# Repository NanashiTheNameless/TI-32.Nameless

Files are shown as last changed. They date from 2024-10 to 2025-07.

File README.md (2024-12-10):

# TI-32

## NamelessNanashi version with erroring towards my personal preferences, no warranty of any kind, not yet tested, DO NOT EXPECT TO WORK PERFECTLY YET

built pcb

"Buy Me A Coffee" (https://buymeacoffee.com/contactchrh)

## Documentation

Read the DOCUMENTATION.md file

## Video

YouTube (https://www.youtube.com/watch?v=Bicjxl4EcJg)

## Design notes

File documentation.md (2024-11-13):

# ESP32 Code Deployment and Server Setup Documentation

## 1. Downloading Code to the ESP32

1. **Open the Arduino IDE**:
   - Open the `.ino` file located in the `esp32` directory using the Arduino IDE.

2. **Configure Secrets**:
   - Navigate to the `secrets.h` file.
   - Fill in the required information (such as WiFi credentials, Hardware Pins, etc.) as specified by your project.

3. **Obtain Server IP Address**:
   - Refer to the [Server Setup](#3-running-the-server) section to get the IP address of your server.
   - Update the IP address in your `secrets.h` to match the server IP.

4. **Flash the ESP32**:
   - Follow the hardware documentation to upload the code to your ESP32.

## 2. Wiring Instructions

1. **Add Wiring Picture**:
   _(Insert image here)_

2. **Wiring Configuration**:
   - Wiring configurations may vary depending on the ESP32 model you're using.
   - Refer to your specific hardware's datasheet for pin configurations.

## 3. Running the Server

1. **Prerequisites**:
   - Ensure you have [Node.js](https://nodejs.org/) and npm (Node Package Manager) installed on your machine.

2. **Install Server Dependencies**:
   - Navigate to the `server` directory in your terminal or command prompt.
   - Run the following command to install the necessary dependencies:

     ```bash
     npm install
     ```

3. **Start the Server**:
   - To run the server, execute the following command:

     ```bash
     node index.mjs
     ```

## 4. Retrieving Your Server IP Address

To obtain the server's IP address (required for configuration in `secrets.h`):

### On Windows

1. Open the Command Prompt by searching for "cmd" in the start menu or pressing `Win + R` and typing `cmd`.
2. Run the following command:

   ```bash
   ipconfig
   ```

3. Locate your specific network adapter (e.g., Wi-Fi or Ethernet).
4. Use the IPv4 address associated with that network adapter. This will be the server's IP address.

---

### Additional Notes

- Ensure your ESP32 and server are connected to the same network.
- If you encounter issues with the server or ESP32 connectivity, verify firewall settings and network configurations.

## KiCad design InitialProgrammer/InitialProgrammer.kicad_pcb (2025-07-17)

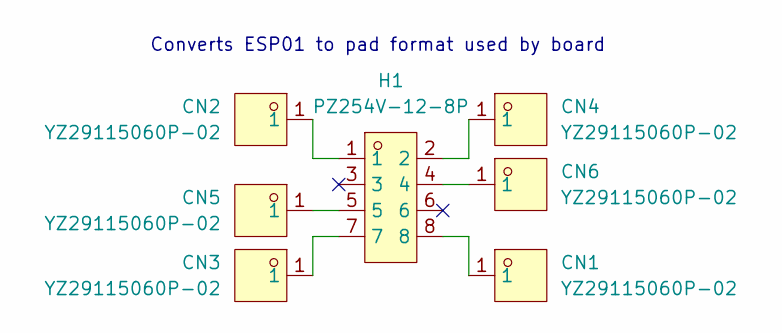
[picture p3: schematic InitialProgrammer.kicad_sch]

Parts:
CN1, CN2, CN3, CN4, CN5, CN6: YZ29115060P-02; TESTPOINT-SMD_BD2.0-D0.7; LCSC Part C5157350
H1: PZ254V-12-8P; HDR-TH_8P-P2.54-V-M-R2-C4-S2.54; LCSC Part C492421

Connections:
unnamed: CN1.1, H1.8
unnamed: CN2.1, H1.1
unnamed: CN3.1, H1.7
unnamed: CN4.1, H1.2
unnamed: CN5.1, H1.5
unnamed: CN6.1, H1.4

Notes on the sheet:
Converts ESP01 to pad format used by board

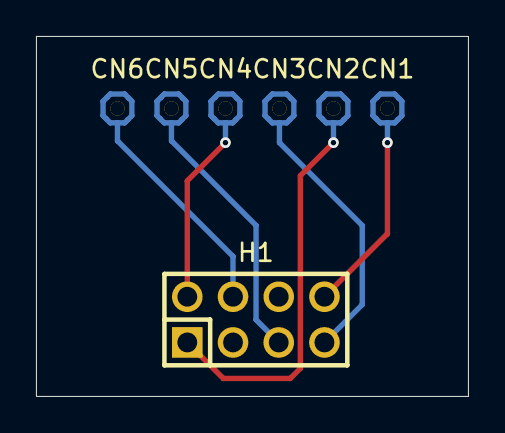
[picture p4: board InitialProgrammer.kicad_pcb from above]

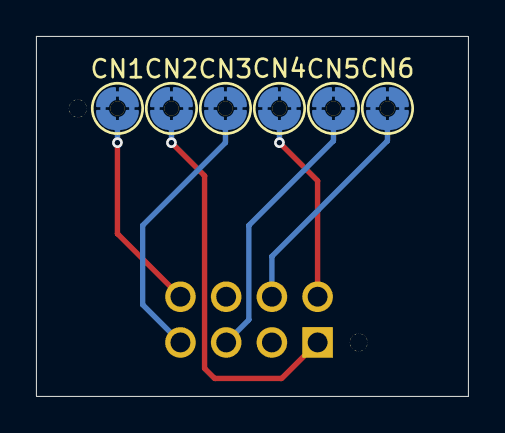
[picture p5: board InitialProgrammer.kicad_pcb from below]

Board: 2 copper layers, 24.0 x 20.0 mm, 7 parts (6 on the bottom side), 6 nets.

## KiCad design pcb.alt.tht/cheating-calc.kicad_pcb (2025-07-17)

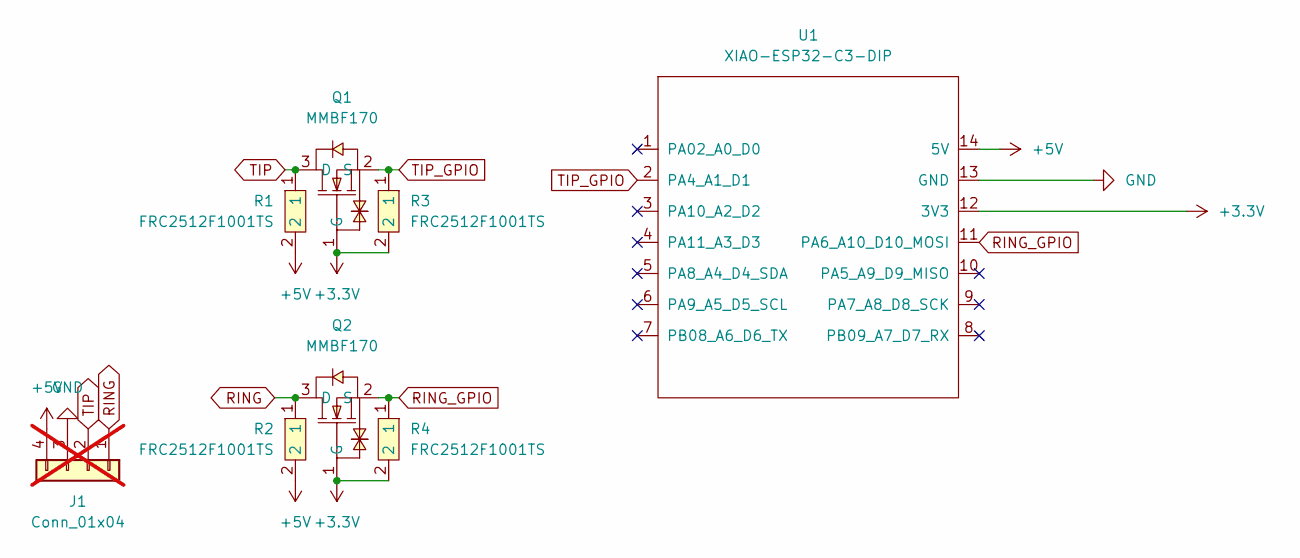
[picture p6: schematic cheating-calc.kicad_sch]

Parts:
J1: Conn_01x04; PinHeader_1x04_P2.54mm_Vertical; not fitted
Q1, Q2: MMBF170; SOT-23-3_L2.9-W1.6-P1.90-LS2.8-BR; LCSC Part C130879
R1, R2, R3, R4: FRC2512F1001TS; R2512; LCSC Part C2960683
U1: XIAO-ESP32-C3-DIP

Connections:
+3.3V: Q1.1 (G), Q2.1 (G), R3.2, R4.2, U1.12 (3V3)
+5V: J1.4, R1.2, R2.2, U1.14 (5V)
GND: J1.3, U1.13 (GND)
RING: J1.1, Q2.3 (D), R2.1
RING_GPIO: Q2.2 (S), R4.1, U1.11 (PA6_A10_D10_MOSI)
TIP: J1.2, Q1.3 (D), R1.1
TIP_GPIO: Q1.2 (S), R3.1, U1.2 (PA4_A1_D1)

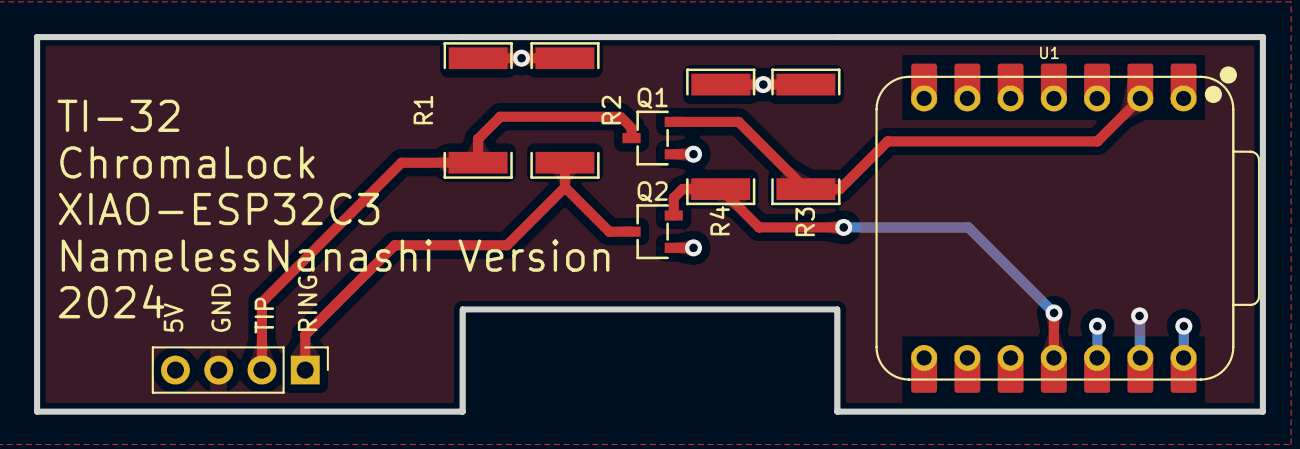
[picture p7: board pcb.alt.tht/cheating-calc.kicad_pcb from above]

Board: 2 copper layers, 72.0 x 22.0 mm, 8 parts (0 on the bottom side), 7 nets.

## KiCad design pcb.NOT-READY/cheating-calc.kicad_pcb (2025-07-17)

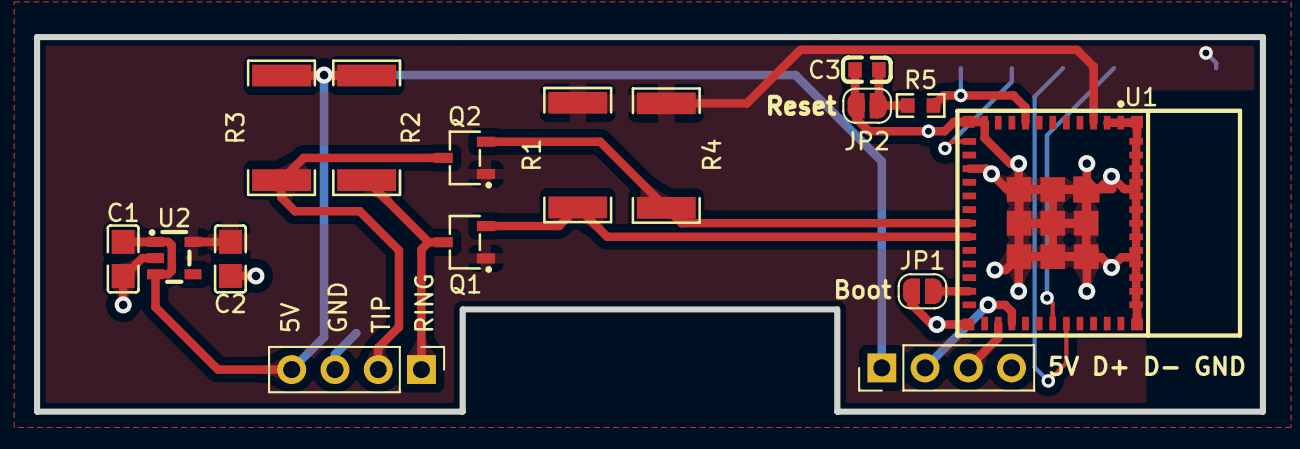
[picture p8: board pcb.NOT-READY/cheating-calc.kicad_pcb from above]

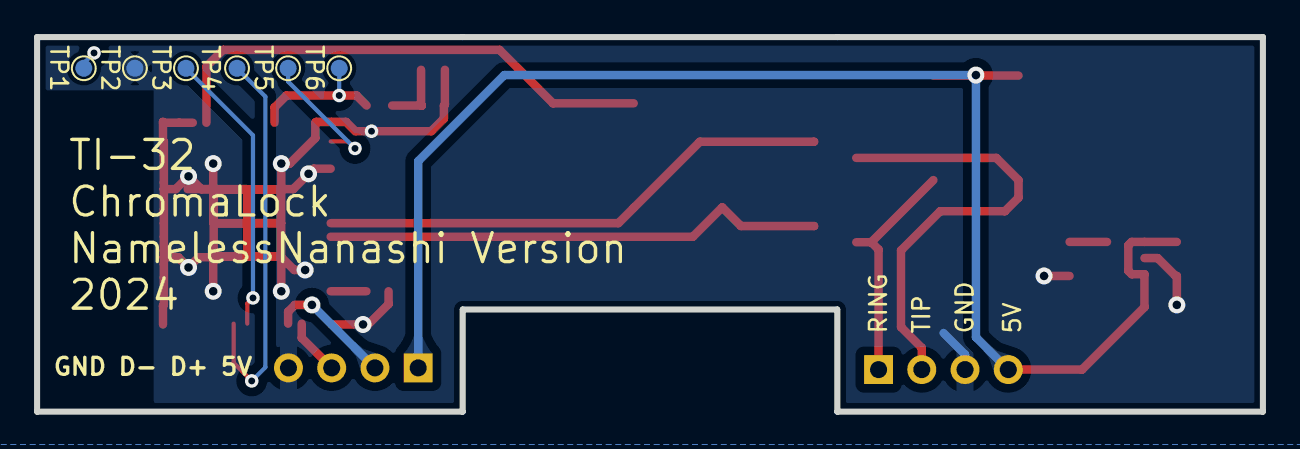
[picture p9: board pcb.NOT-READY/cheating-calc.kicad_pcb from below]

Board: 2 copper layers, 72.0 x 22.0 mm, 22 parts (6 on the bottom side), 15 nets.

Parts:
C1, C2: CL21B105KPFNNNE; C0805
C3: CC0603KRX7R9BB104; C0603
J1, J2: Conn_01x04; PinHeader_1x04_P2.54mm_Vertical
JP1, JP2: SolderJumper_2_Open; SolderJumper-2_P1.3mm_Open_RoundedPad1.0x1.5mm
Q1, Q2: MMBF170; SOT-23-3_L2.9-W1.6-P1.90-LS2.8-BR
R1, R2, R3, R4: FRC2512F1001TS; R2512
R5: 0603WAF1002T5E; R0603
TP1, TP2, TP3, TP4, TP5, TP6: TestPoint; TestPoint_Pad_D1.0mm
U1: ESP32-C3-MINI-1-N4; WIFIM-SMD_ESP32-C3-MINI-1
U2: TPLP5907MFX-3.3; SOT-23-5_L2.9-W1.6-P0.95-LS2.8-BR

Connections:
+3.3V: C2.1, Q1.1 (G), Q2.1 (G), R1.2, R4.2, TP1.1, U1.3 (3V3), U2.5 (VOUT)
+5V: C1.1, J1.4, J2.1, R2.2, R3.2, U2.1 (VIN), U2.3 (EN)
/D+: J2.2, U1.27 (IO19)
/D-: J2.3, U1.26 (IO18)
GND: C1.2, C2.2, C3.1, J1.3, J2.4, JP1.1 (A), JP2.1 (A), TP2.1, U1.1 (GND), U1.2 (GND), U1.11 (GND), U1.14 (GND), U1.36 (GND), U1.37 (GND), U1.38 (GND), U1.39 (GND), U1.40 (GND), U1.41 (GND), U1.42 (GND), U1.43 (GND), U1.44 (GND), U1.45 (GND), U1.46 (GND), U1.47 (GND), U1.48 (GND), U1.49 (GND), U1.50 (GND), U1.51 (GND), U1.52 (GND), U1.53 (GND), U2.2 (GND)
unnamed: JP1.2 (B), U1.23 (IO9)
unnamed: C3.2, JP2.2 (B), R5.1
unnamed: R5.2, TP6.1, U1.8 (EN)
unnamed: TP5.1, U1.12 (IO0)
unnamed: TP3.1, U1.30 (RXD0)
unnamed: TP4.1, U1.31 (TXD0)
RING: J1.1, Q1.3 (D), R2.1
RING_GPIO: Q1.2 (S), R1.1, U1.19 (IO5)
TIP: J1.2, Q2.3 (D), R3.1
TIP_GPIO: Q2.2 (S), R4.1, U1.18 (IO4)

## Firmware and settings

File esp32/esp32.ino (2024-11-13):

// Project: TI-32 v0.1
// Author:  ChromaLock
// Date:    2024

#include "./secrets.h"
#include "./launcher.h"
#include <TICL.h>
#include <CBL2.h>
#include <TIVar.h>
#include <WiFi.h>
#include <WiFiClientSecure.h>
#include <WiFiClient.h>
#include <HTTPClient.h>
#include <UrlEncode.h>
#include <Preferences.h>

// #define CAMERA

#ifdef CAMERA
#include <esp_camera.h>
#define CAMERA_MODEL_XIAO_ESP32S3
#include "./camera_pins.h"
#include "./camera_index.h"
#endif

constexpr auto TIP = D1;
constexpr auto RING = D10;
constexpr auto MAXHDRLEN = 16;
constexpr auto MAXDATALEN = 4096;
constexpr auto MAXARGS = 5;
constexpr auto MAXSTRARGLEN = 256;
constexpr auto PICSIZE = 756;
constexpr auto PICVARSIZE = PICSIZE + 2;
constexpr auto PASSWORD = 69420;

CBL2 cbl;
Preferences prefs;

// whether or not the user has entered the password
bool unlocked = false;

// Arguments
int currentArg = 0;
char strArgs[MAXARGS][MAXSTRARGLEN];
double realArgs[MAXARGS];

// the command to execute
int command = -1;
// whether or not the operation has completed
bool status = 0;
// whether or not the operation failed
bool error = 0;
// error or success message
char message[MAXSTRARGLEN];
// list data
constexpr auto LISTLEN = 256;
constexpr auto LISTENTRYLEN = 20;
char list[LISTLEN][LISTENTRYLEN];
// http response
constexpr auto MAXHTTPRESPONSELEN = 4096;
char response[MAXHTTPRESPONSELEN];
// image variable (96x63)
uint8_t frame[PICVARSIZE] = {PICSIZE & 0xff, PICSIZE >> 8};
String fullResponse;
const int PAGE_SIZE = 100;
int PAGE_PAGE = 0; 

void connect();
void disconnect();
void gpt();
void send();
void launcher();
void snap();
void solve();
void image_list();
void fetch_image();
void fetch_chats();
void send_chat();
void program_list();
void fetch_program();
void sendPage();
void reply();
void clearChat(); 

struct Command
{
  int id;
  const char *name;
  int num_args;
  void (*command_fp)();
  bool wifi;
};

struct Command commands[] = {
    {0, "connect", 0, connect, false},
    {1, "disconnect", 0, disconnect, false},
    {2, "gpt", 1, gpt, true},
    {4, "send", 2, send, true},
    {5, "launcher", 0, launcher, false},
    {7, "snap", 0, snap, false},
    {8, "solve", 1, solve, true},
    {9, "image_list", 1, image_list, true},
    {10, "fetch_image", 1, fetch_image, true},
    {11, "fetch_chats", 2, fetch_chats, true},
    {12, "send_chat", 2, send_chat, true},
    {13, "program_list", 1, program_list, true},
    {14, "fetch_program", 1, fetch_program, true},
    { 15, "sendPage", 1, sendPage, true },
    { 16, "reply", 1, reply, true },
    { 17, "clearChat", 1, clearChat, true}, 
};

constexpr int NUMCOMMANDS = sizeof(commands) / sizeof(struct Command);
constexpr int MAXCOMMAND = 14;

uint8_t header[MAXHDRLEN];
uint8_t data[MAXDATALEN];

// lowercase letters make strings weird,
// so we have to truncate the string
void fixStrVar(char *str)
{
  int end = strlen(str);
  for (int i = 0; i < end; ++i)
  {
    if (isLowerCase(str[i]))
    {
      --end;
    }
  }
  str[end] = '\0';
}

int onReceived(uint8_t type, enum Endpoint model, int datalen);
int onRequest(uint8_t type, enum Endpoint model, int *headerlen,
              int *datalen, data_callback *data_callback);

void startCommand(int cmd)
{
  command = cmd;
  status = 0;
  error = 0;
  currentArg = 0;
  for (int i = 0; i < MAXARGS; ++i)
  {
    memset(&strArgs[i], 0, MAXSTRARGLEN);
    realArgs[i] = 0;
  }
  strncpy(message, "no command", MAXSTRARGLEN);
}

void setError(const char *err)
{
  Serial.print("ERROR: ");
  Serial.println(err);
  error = 1;
  status = 1;
  command = -1;
  strncpy(message, err, MAXSTRARGLEN);
}

void setSuccess(const char *success)
{
  Serial.print("SUCCESS: ");
  Serial.println(success);
  error = 0;
  status = 1;
  command = -1;
  strncpy(message, success, MAXSTRARGLEN);
}

int sendProgramVariable(const char *name, uint8_t *program, size_t variableSize);

bool camera_sign = false;

void setup()
{
  Serial.begin(115200);
   Serial.println("delay");
    delay(2000); 
  Serial.println("[CBL]");
  delay(1000);

  cbl.setLines(TIP, RING);
  cbl.resetLines();
  cbl.setupCallbacks(header, data, MAXDATALEN, onReceived, onRequest);
  // cbl.setVerbosity(true, (HardwareSerial *)&Serial);

  pinMode(TIP, INPUT);
  pinMode(RING, INPUT);

  Serial.println("[preferences]");
  prefs.begin("ccalc", false);
  auto reboots = prefs.getUInt("boots", 0);
  Serial.print("reboots: ");
  Serial.println(reboots);
  prefs.putUInt("boots", reboots + 1);
  prefs.end();

#ifdef CAMERA
  Serial.println("[camera]");

  camera_config_t config;
  config.ledc_channel = LEDC_CHANNEL_0;
  config.ledc_timer = LEDC_TIMER_0;
  config.pin_d0 = Y2_GPIO_NUM;
  config.pin_d1 = Y3_GPIO_NUM;
  config.pin_d2 = Y4_GPIO_NUM;
  config.pin_d3 = Y5_GPIO_NUM;
  config.pin_d4 = Y6_GPIO_NUM;
  config.pin_d5 = Y7_GPIO_NUM;
  config.pin_d6 = Y8_GPIO_NUM;
  config.pin_d7 = Y9_GPIO_NUM;
  config.pin_xclk = XCLK_GPIO_NUM;
  config.pin_pclk = PCLK_GPIO_NUM;
  config.pin_vsync = VSYNC_GPIO_NUM;
  config.pin_href = HREF_GPIO_NUM;
  config.pin_sscb_sda = SIOD_GPIO_NUM;
  config.pin_sscb_scl = SIOC_GPIO_NUM;
  config.pin_pwdn = PWDN_GPIO_NUM;
  config.pin_reset = RESET_GPIO_NUM;
  config.xclk_freq_hz = 20000000;
  config.frame_size = FRAMESIZE_UXGA;
  // this needs to be pixformat grayscale in the future
  config.pixel_format = PIXFORMAT_JPEG; // for streaming
  config.grab_mode = CAMERA_GRAB_WHEN_EMPTY;
  config.fb_location = CAMERA_FB_IN_PSRAM;
  config.jpeg_quality = 12;
  config.fb_count = 1;

  // if PSRAM IC present, init with UXGA resolution and higher JPEG quality
  //                      for larger pre-allocated frame buffer.
  if (config.pixel_format == PIXFORMAT_JPEG)
  {
    if (psramFound())
    {
      config.jpeg_quality = 10;
      config.fb_count = 2;
      config.grab_mode = CAMERA_GRAB_LATEST;
    }
    else
    {
      // Limit the frame size when PSRAM is not available
      config.frame_size = FRAMESIZE_SVGA;
      config.fb_location = CAMERA_FB_IN_DRAM;
    }
  }
  else
  {
    // Best option for face detection/recognition
    config.frame_size = FRAMESIZE_240X240;
#if CONFIG_IDF_TARGET_ESP32S3
    config.fb_count = 2;
#endif
  }

  // camera init
  esp_err_t err = esp_camera_init(&config);
  if (err != ESP_OK)
  {
    Serial.printf("Camera init failed with error 0x%x\n", err);
    return;
  }
  else
  {
    Serial.println("camera ready");
    camera_sign = true; // Camera initialization check passes
  }

  sensor_t *s = esp_camera_sensor_get();
  // enable grayscale
  s->set_special_effect(s, 2);
#endif

  strncpy(message, "default message", MAXSTRARGLEN);
  delay(100);
  memset(data, 0, MAXDATALEN);
  memset(header, 0, 16);
  Serial.println("[ready]");
}

void (*queued_action)() = NULL;

void loop()
{
  if (queued_action)
  {
    // dont ask me why you need this, but it fails otherwise.
    // probably relates to a CBL2 timeout thing?
    delay(1000);
    Serial.println("executing queued actions");
    // dont ask me
    void (*tmp)() = queued_action;
    queued_action = NULL;
    tmp();
  }
  if (command >= 0 && command <= MAXCOMMAND)
  {
    for (int i = 0; i < NUMCOMMANDS; ++i)
    {
      if (commands[i].id == command && commands[i].num_args == currentArg)
      {
        if (commands[i].wifi && !WiFi.isConnected())
        {
          setError("wifi not connected");
        }
        else
        {
          Serial.print("processing command: ");
          Serial.println(commands[i].name);
          commands[i].command_fp();
        }
      }
    }
  }
  cbl.eventLoopTick();
}

int onReceived(uint8_t type, enum Endpoint model, int datalen)
{
  char varName = header[3];

  Serial.print("unlocked: ");
  Serial.println(unlocked);

  // check for password
  if (!unlocked && varName == 'P')
  {
    auto password = TIVar::realToLong8x(data, model);
    if (password == PASSWORD)
    {
      Serial.println("successful unlock");
      unlocked = true;
      return 0;
    }
    else
    {
      Serial.println("failed unlock");
    }
  }

  if (!unlocked)
  {
    return -1;
  }

  // check for command
  if (varName == 'C')
  {
    if (type != VarTypes82::VarReal)
    {
      return -1;
    }
    int cmd = TIVar::realToLong8x(data, model);
    if (cmd >= 0 && cmd <= MAXCOMMAND)
    {
      Serial.print("command: ");
      Serial.println(cmd);
      startCommand(cmd);
      return 0;
    }
    else
    {
      Serial.print("invalid command: ");
      Serial.println(cmd);
      return -1;
    }
    
  }
      if (varName == 'V') {
    if (type != VarTypes82::VarReal) {
      return -1;
    }
    PAGE_PAGE = TIVar::realToLong8x(data, model);
    Serial.print("Received page number: ");
    Serial.println(PAGE_PAGE);
    sendPage();
    return 0;
  }

  if (varName == 'X') {
    Serial.println("Recieved var X");
    if (type != VarTypes82::VarReal) {
      Serial.println("var x not equal vartypes82:varreal");
      return -1;

    }
    Serial.println("Reset fullResponse to empty");
    fullResponse = "";
    
    return 0;
  }

  if (currentArg >= MAXARGS)
  {
    Serial.println("argument overflow");
    setError("argument overflow");
    return -1;
  }

  switch (type)
  {
  case VarTypes82::VarString:
    Serial.print("len: ");
    strncpy(strArgs[currentArg++], TIVar::strVarToString8x(data, model).c_str(), MAXSTRARGLEN);
    fixStrVar(strArgs[currentArg - 1]);
    Serial.print("Str");
    Serial.print(currentArg - 1);
    Serial.print(" ");
    Serial.println(strArgs[currentArg - 1]);
    break;
  case VarTypes82::VarReal:
    realArgs[currentArg++] = TIVar::realToFloat8x(data, model);
    Serial.print("Real");
    Serial.print(currentArg - 1);
    Serial.print(" ");
    Serial.println(realArgs[currentArg - 1]);
    break;
  default:
    // maybe set error here?
    return -1;
  }
  return 0;
}

uint8_t frameCallback(int idx)
{
  return frame[idx];
}

char varIndex(int idx)
{
  return '0' + (idx == 9 ? 0 : (idx + 1));
}

int onRequest(uint8_t type, enum Endpoint model, int *headerlen, int *datalen, data_callback *data_callback)
{
  char varName = header[3];
  char strIndex = header[4];
  char strname[5] = {'S', 't', 'r', varIndex(strIndex), 0x00};
  char picname[5] = {'P', 'i', 'c', varIndex(strIndex), 0x00};
  Serial.print("request for ");
  Serial.println(varName == 0xaa ? strname : varName == 0x60 ? picname
                                                             : (const char *)&header[3]);
  memset(header, 0, sizeof(header));
  switch (varName)
  {
  case 0x60:
    if (type != VarTypes82::VarPic)
    {
      return -1;
    }
    *datalen = PICVARSIZE;
    TIVar::intToSizeWord(*datalen, &header[0]);
    header[2] = VarTypes82::VarPic;
    header[3] = 0x60;
    header[4] = strIndex;
    *data_callback = frameCallback;
    break;
  case 0xAA:
    if (type != VarTypes82::VarString)
    {
      return -1;
    }
    // TODO right now, the only string variable will be the message, but ill need to allow for other vars later
    *datalen = TIVar::stringToStrVar8x(String(message), data, model);
    TIVar::intToSizeWord(*datalen, header);
    header[2] = VarTypes82::VarString;
    header[3] = 0xAA;
    // send back as same variable that was requested
    header[4] = strIndex;
    *headerlen = 13;
    break;
  case 'E':
    if (type != VarTypes82::VarReal)
    {
      return -1;
    }
    *datalen = TIVar::longToReal8x(error, data, model);
    TIVar::intToSizeWord(*datalen, header);
    header[2] = VarTypes82::VarReal;
    header[3] = 'E';
    header[4] = '\0';
    *headerlen = 13;
    break;
  case 'S':
    if (type != VarTypes82::VarReal)
    {
      return -1;
    }
    *datalen = TIVar::longToReal8x(status, data, model);
    TIVar::intToSizeWord(*datalen, header);
    header[2] = VarTypes82::VarReal;
    header[3] = 'S';
    header[4] = '\0';
    *headerlen = 13;
    break;
  default:
    return -1;
  }
  return 0;
}

int makeRequest(String url, char *result, int resultLen, size_t *len)
{
  memset(result, 0, resultLen);

#ifdef SECURE
  WiFiClientSecure client;
  client.setInsecure();
#else
  WiFiClient client;
#endif
  HTTPClient http;
  http.setAuthorization(HTTP_USERNAME, HTTP_PASSWORD);

  Serial.println(url);
  http.begin(client, url.c_str());

  // Send HTTP GET request
  int httpResponseCode = http.GET();
  Serial.print(url);
  Serial.print(" ");
  Serial.println(httpResponseCode);

  int responseSize = http.getSize();
  WiFiClient *httpStream = http.getStreamPtr();

  Serial.print("response size: ");
  Serial.println(responseSize);

  if (httpResponseCode != 200)
  {
    return httpResponseCode;
  }

  if (httpStream->available() > resultLen)
  {
    Serial.print("response size: ");
    Serial.print(httpStream->available());
    Serial.println(" is too big");
    return -1;
  }

  while (httpStream->available())
  {
    *(result++) = httpStream->read();
  }
  *len = responseSize;

  http.end();

  return 0;
}

void connect()
{
  const char *ssid = WIFI_SSID;
  const char *pass = WIFI_PASS;
  Serial.print("SSID: ");
  Serial.println(ssid);
  Serial.print("PASS: ");
  Serial.println("<hidden>");
  WiFi.begin(ssid, pass);
  while (WiFi.status() != WL_CONNECTED)
  {
    if (WiFi.status() == WL_CONNECT_FAILED)
    {
      setError("failed to connect");
      return;
    }
  }
  setSuccess("connected");
}

void disconnect()
{
  WiFi.disconnect(true);
  setSuccess("disconnected");
}

void clearChat() {
  fullResponse = "";
}

void reply() {
  Serial.println("Reply action initiated");
  const char* userReply = strArgs[0];
  Serial.print("prompt: ");
  Serial.println(userReply);
  // Append the user's reply to the existing conversation
  fullResponse += "| User: " + String(userReply) + "| AI: ";
  Serial.print("full response: ");
  Serial.println(fullResponse);
  // Send the updated conversation to the server
  auto url = String(SERVER) + String("/gpt/ask?question=") + urlEncode(fullResponse);
  Serial.println("made url");
  Serial.println(url);

  size_t realsize = 0;
  Serial.println("sending request");
  if (makeRequest(url, response, MAXHTTPRESPONSELEN, &realsize)) {
    setError("error making request");
    return;
  }
  Serial.println("request recieved");

  // Update fullResponse with the new AI response
  fullResponse += String(response);

  PAGE_PAGE = 0;  // Reset to first page
  sendPage();
}

void gpt() {
  const char* prompt = strArgs[0];
  Serial.print("prompt: ");
  Serial.println(prompt);

  fullResponse = "User: " + String(prompt) + " | AI: ";

  auto url = String(SERVER) + String("/gpt/ask?question=") + urlEncode(String(prompt));

  size_t realsize = 0;
  if (makeRequest(url, response, MAXHTTPRESPONSELEN, &realsize)) {
    setError("error making request");
    return;
  }

  fullResponse += String(response);
  Serial.print("Full response: ");
  Serial.println(fullResponse);

  PAGE_PAGE = 0; 
  sendPage();
}

void sendPage() {
  int start = PAGE_PAGE * PAGE_SIZE;
  String pageContent = fullResponse.substring(start, min(start + PAGE_SIZE, (int)fullResponse.length()));
  
  strncpy(message, pageContent.c_str(), MAXSTRARGLEN);
  setSuccess(message);
}

void send()
{
  const char *recipient = strArgs[0];
  const char *message = strArgs[1];
  Serial.print("sending \"");
  Serial.print(message);
  Serial.print("\" to \"");
  Serial.print(recipient);
  Serial.println("\"");
  setSuccess("OK: sent");
}

void _sendLauncher()
{
  sendProgramVariable("TI32", __launcher_var, __launcher_var_len);
}

void launcher()
{
  // we have to queue this action, since otherwise the transfer fails
  // due to the CBL2 library still using the lines
  queued_action = _sendLauncher;
  setSuccess("queued transfer");
}

void snap()
{
#ifdef CAMERA
  if (!camera_sign)
  {
    setError("camera failed to initialize");
  }
#else
  setError("pictures not supported");
#endif
}

void solve()
{
#ifdef CAMERA
  if (!camera_sign)
  {
    setError("camera failed to initialize");
  }
#else
  setError("pictures not supported");
#endif
}

void image_list()
{
  int page = realArgs[0];
  auto url = String(SERVER) + String("/image/list?p=") + urlEncode(String(page));

  size_t realsize = 0;
  if (makeRequest(url, response, MAXSTRARGLEN, &realsize))
  {
    setError("error making request");
    return;
  }

  Serial.print("response: ");
  Serial.println(response);

  setSuccess(response);
}

void fetch_image()
{
  memset(frame + 2, 0, 756);
  // fetch image and put it into the frame variable
  int id = realArgs[0];
  Serial.print("id: ");
  Serial.println(id);

  auto url = String(SERVER) + String("/image/get?id=") + urlEncode(String(id));

  size_t realsize = 0;
  if (makeRequest(url, response, MAXHTTPRESPONSELEN, &realsize))
  {
    setError("error making request");
    return;
  }

  if (realsize != PICSIZE)
  {
    Serial.print("response size:");
    Serial.println(realsize);
    setError("bad image size");
    return;
  }

  // load the image
  frame[0] = realsize & 0xff;
  frame[1] = (realsize >> 8) & 0xff;
  memcpy(&frame[2], response, 756);

  setSuccess(response);
}

void fetch_chats()
{
  int room = realArgs[0];
  int page = realArgs[1];
  auto url = String(SERVER) + String("/chats/messages?p=") + urlEncode(String(page)) + String("&c=") + urlEncode(String(room));

  size_t realsize = 0;
  if (makeRequest(url, response, MAXSTRARGLEN, &realsize))
  {
    setError("error making request");
    return;
  }

  Serial.print("response: ");
  Serial.println(response);

  setSuccess(response);
}

void send_chat()
{
  int room = realArgs[0];
  const char *msg = strArgs[1];

  auto url = String(SERVER) +
             String("/chats/send?c=") +
             urlEncode(String(room)) +
             String("&m=") +
             urlEncode(String(msg)) +
             String("&id=") +
             urlEncode(String(CHAT_NAME));

  size_t realsize = 0;
  if (makeRequest(url, response, MAXSTRARGLEN, &realsize))
  {
    setError("error making request");
    return;
  }

  Serial.print("response: ");
  Serial.println(response);

  setSuccess(response);
}

void program_list()
{
  int page = realArgs[0];
  auto url = String(SERVER) + String("/programs/list?p=") + urlEncode(String(page));

  size_t realsize = 0;
  if (makeRequest(url, response, MAXSTRARGLEN, &realsize))
  {
    setError("error making request");
    return;
  }

  Serial.print("response: ");
  Serial.println(response);

  setSuccess(response);
}

char programName[256];
char programData[4096];
size_t programLength;

void _resetProgram()
{
  memset(programName, 0, 256);
  memset(programData, 0, 4096);
  programLength = 0;
}

void _sendDownloadedProgram()
{
  if (sendProgramVariable(programName, (uint8_t *)programData, programLength))
  {
    Serial.println("failed to transfer requested download");
    Serial.print(programName);
    Serial.print("(");
    Serial.print(programLength);
    Serial.println(")");
  }
  _resetProgram();
}

void fetch_program()
{
  int id = realArgs[0];
  Serial.print("id: ");
  Serial.println(id);

  _resetProgram();

  auto url = String(SERVER) + String("/programs/get?id=") + urlEncode(String(id));

  if (makeRequest(url, programData, 4096, &programLength))
  {
    setError("error making request for program data");
    return;
  }

  size_t realsize = 0;
  auto nameUrl = String(SERVER) + String("/programs/get_name?id=") + urlEncode(String(id));
  if (makeRequest(nameUrl, programName, 256, &realsize))
  {
    setError("error making request for program name");
    return;
  }

  queued_action = _sendDownloadedProgram;

  setSuccess("queued download");
}

/// OTHER FUNCTIONS

int sendProgramVariable(const char *name, uint8_t *program, size_t variableSize)
{
  Serial.print("transferring: ");
  Serial.print(name);
  Serial.print("(");
  Serial.print(variableSize);
  Serial.println(")");

  int dataLength = 0;

  // IF THIS ISNT SET TO COMP83P, THIS DOESNT WORK
  // seems like ti-84s cant silent transfer to each other
  uint8_t msg_header[4] = {COMP83P, RTS, 13, 0};

  uint8_t rtsdata[13] = {variableSize & 0xff, variableSize >> 8, VarTypes82::VarProgram, 0x00, 0x00, 0x00, 0x00, 0x00, 0x00, 0x00, 0x00, 0x00, 0x00};
  int nameSize = strlen(name);
  if (nameSize == 0)
  {
    return 1;
  }
  memcpy(&rtsdata[3], name, min(nameSize, 8));

  auto rtsVal = cbl.send(msg_header, rtsdata, 13);
  if (rtsVal)
  {
    Serial.print("rts return: ");
    Serial.println(rtsVal);
    return rtsVal;
  }

  cbl.resetLines();
  auto ackVal = cbl.get(msg_header, NULL, &dataLength, 0);
  if (ackVal || msg_header[1] != ACK)
  {
    Serial.print("ack return: ");
    Serial.println(ackVal);
    return ackVal;
  }

  auto ctsRet = cbl.get(msg_header, NULL, &dataLength, 0);
  if (ctsRet || msg_header[1] != CTS)
  {
    Serial.print("cts return: ");
    Serial.println(ctsRet);
    return ctsRet;
  }

  msg_header[1] = ACK;
  msg_header[2] = 0x00;
  msg_header[3] = 0x00;
  ackVal = cbl.send(msg_header, NULL, 0);
  if (ackVal || msg_header[1] != ACK)
  {
    Serial.print("ack cts return: ");
    Serial.println(ackVal);
    return ackVal;
  }

  msg_header[1] = DATA;
  msg_header[2] = variableSize & 0xff;
  msg_header[3] = (variableSize >> 8) & 0xff;
  auto dataRet = cbl.send(msg_header, program, variableSize);
  if (dataRet)
  {
    Serial.print("data return: ");
    Serial.println(dataRet);
    return dataRet;
  }

  ackVal = cbl.get(msg_header, NULL, &dataLength, 0);
  if (ackVal || msg_header[1] != ACK)
  {
    Serial.print("ack data: ");
    Serial.println(ackVal);
    return ackVal;
  }

  msg_header[1] = EOT;
  msg_header[2] = 0x00;
  msg_header[3] = 0x00;
  auto eotVal = cbl.send(msg_header, NULL, 0);
  if (eotVal)
  {
    Serial.print("eot return: ");
    Serial.println(eotVal);
    return eotVal;
  }

  Serial.print("transferred: ");
  Serial.println(name);
  return 0;
}

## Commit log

2024-09-17 add all of my personal changes from my local machine
    [cheating-calc-B_Cu.gbr, cheating-calc-B_Mask.gbr, cheating-calc-B_Paste.gbr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]
2024-09-17 update gitignore and clear out useless files
    [cheating-calc-CuBottom.gbr, cheating-calc-CuTop.gbr, cheating-calc-EdgeCuts.gbr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]
2024-09-20 tweak silkscreen and schematic
    [cheating-calc.kicad_pcb, cheating-calc.kicad_sch]
2024-10-19 change layout parts and esp32 module choice for space savings
    [cheating-calc.kicad_pcb, cheating-calc.kicad_sch]
2024-10-19 add missing datasheet to module
    [cheating-calc.kicad_pcb]
2024-10-19 update LDO regulator to be a genuine TI (and add redundency for other versions in schem)
    [cheating-calc.kicad_pcb, cheating-calc.kicad_sch]
2024-10-20 add rounded version of my NOT-READY PCB
    [cheating-calc.kicad_pcb, cheating-calc.kicad_sch]
2024-11-13 Update regulator chip and remove rounded versions
    [cheating-calc.kicad_pcb, cheating-calc.kicad_sch]
2024-11-13 add (updated) rounded versions
    [cheating-calc.kicad_pcb, cheating-calc.kicad_sch]
2024-11-13 update routing
    [cheating-calc.kicad_pcb, cheating-calc.kicad_sch]
2024-11-13 update cap
    [cheating-calc.kicad_pcb, cheating-calc.kicad_sch]
2024-11-17 Update PCB to add programming pins
    [cheating-calc.kicad_pcb, cheating-calc.kicad_sch]
2024-12-10 update to add 3d models
    [cheating-calc.kicad_pcb]
2024-12-11 update to use a cheaper more avalible LDO
    [cheating-calc.kicad_pcb, cheating-calc.kicad_sch]
2025-07-17 update and add tht version
    [InitialProgrammer.kicad_pcb, InitialProgrammer.kicad_sch, cheating-calc.kicad_pcb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]
